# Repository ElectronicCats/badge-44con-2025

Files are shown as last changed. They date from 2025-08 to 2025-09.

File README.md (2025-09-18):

# Hardware config 

Attention! Reading this README is essential—not only for a better understanding and experience, but also to avoid damaging the badge.

The 44con can operate either with the ESP32 or with the shield. It is important to note that, for the badge to function correctly, at least one of the two must be soldered. Otherwise, the badge will not work.

When the shield is installed, the badge will only operate the OLED display with the built-in mini-game.

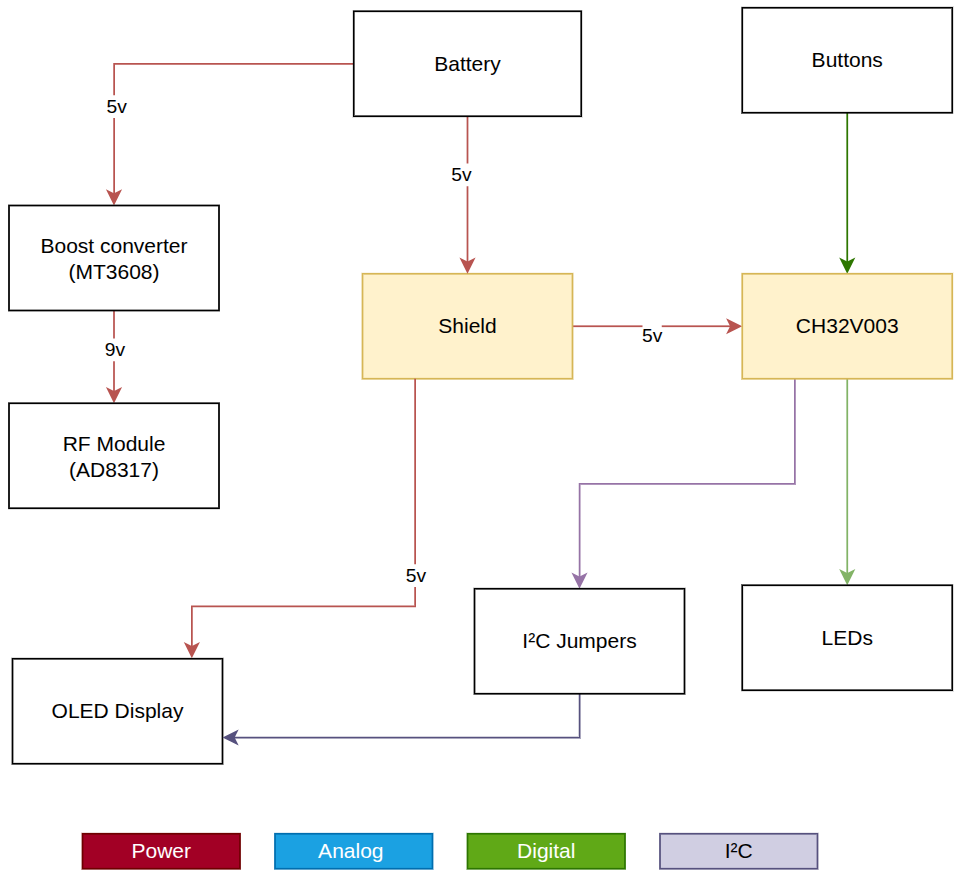
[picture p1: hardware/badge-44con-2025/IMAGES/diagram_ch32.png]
Diagram CH32


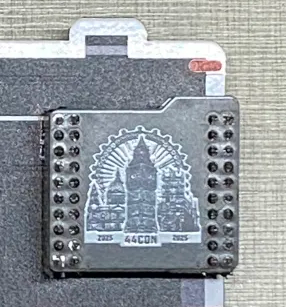
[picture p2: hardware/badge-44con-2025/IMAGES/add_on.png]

(Badge with shield)

# 
If you solder the shield you only need to solder the bended pins shown at the photo at least, if you decide to solder more pins just for fun go ahead.



#
For the best possible experience with the badge, it is recommended to solder the ESP32 with the following components:

ESP32 Wemos D1 module



Buzzer

MT3608 Boost Converter

AD8317 RF Detector

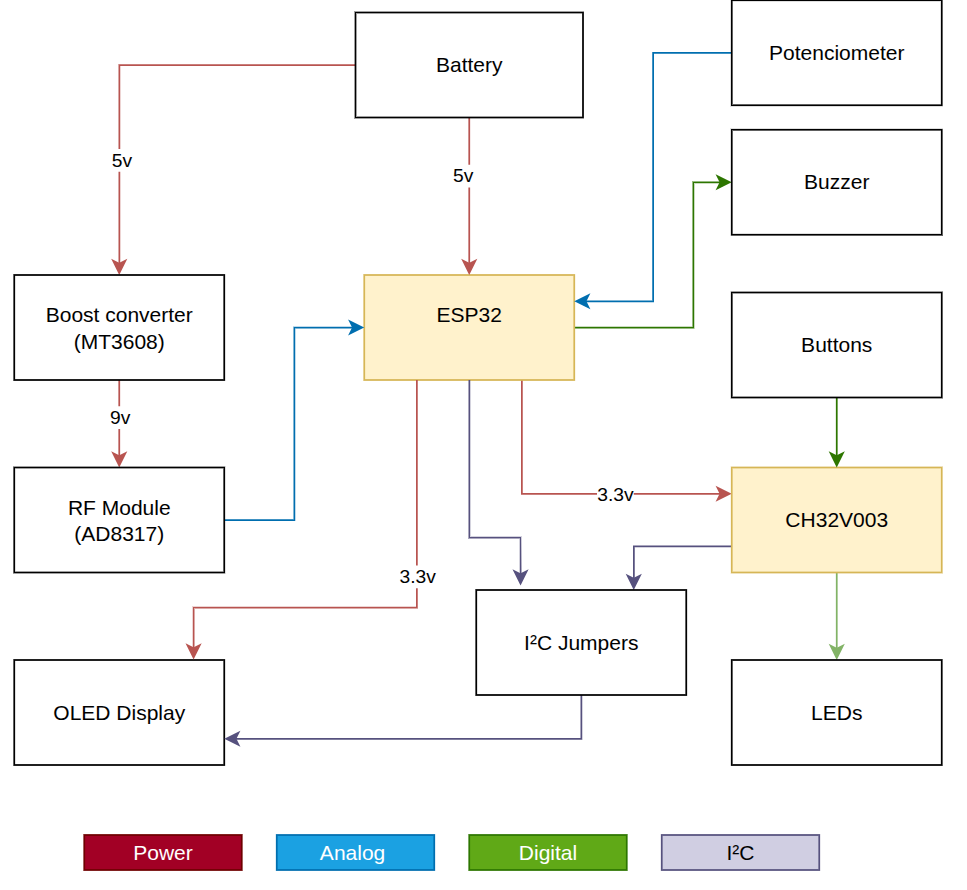
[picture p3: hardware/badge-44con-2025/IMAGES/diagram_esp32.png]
diagram esp32


# Addon 

The Addon is located on the front side of the board, and the connections are as follows:

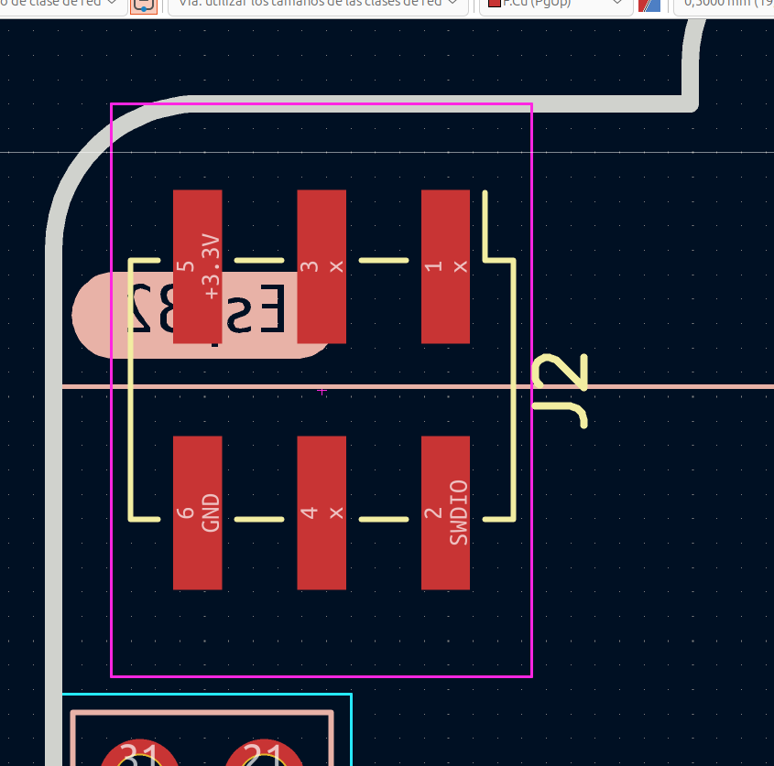
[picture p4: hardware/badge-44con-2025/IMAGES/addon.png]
addon


# Boost circuit
It raises the voltage from 5 V to 9 V for the RF detector. The Boost circuit must be placed on the rear side of the board, as shown in the image. 

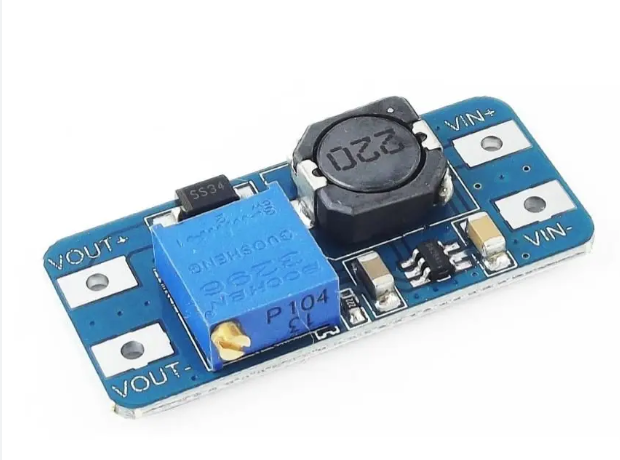
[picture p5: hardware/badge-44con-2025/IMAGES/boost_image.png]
Boost image

<br>
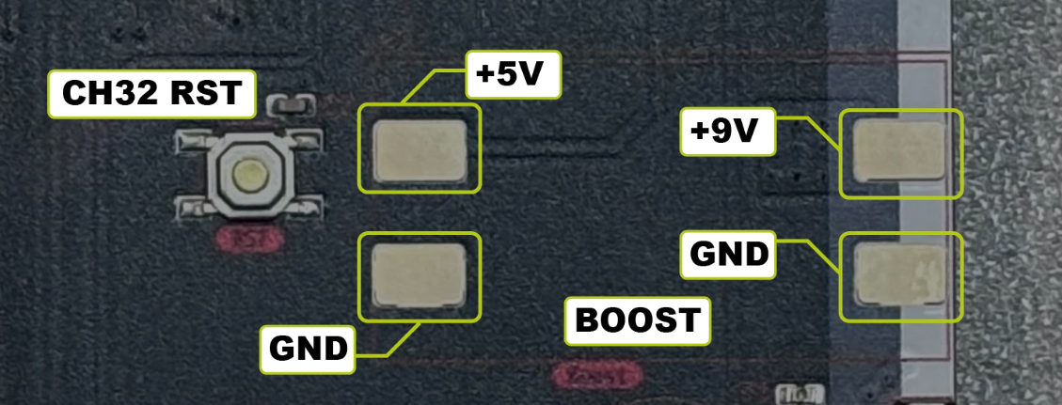
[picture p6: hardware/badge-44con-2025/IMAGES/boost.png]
Boost diagram


# I²C jumper 
The I²C jumpers are located on the rear side of the board (JP3 for SCL and JP2 for SDA). These determine whether the ESP32 or the CH32 will control the OLED display. By default, the CH32 controls the display. To switch control to the ESP32, the pads must be cut to separate them (as indicated in the image), and then the central pad must be soldered to the opposite pad. In the case of JP2, solder the central pad to the left pad, and for JP3, solder it to the right pad.

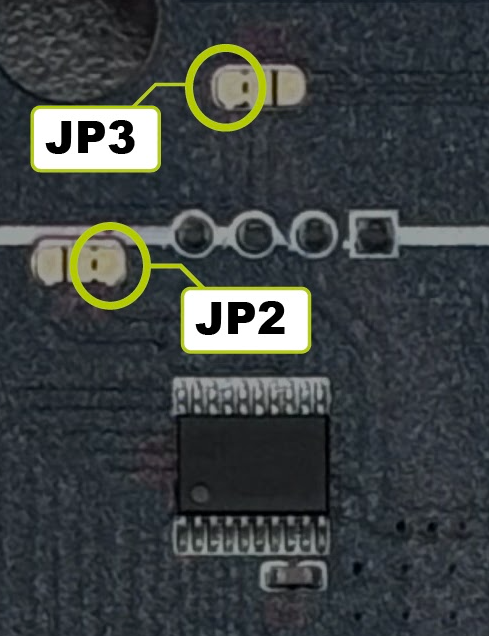
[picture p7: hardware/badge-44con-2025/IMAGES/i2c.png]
I2C Diagram


# Potenciometer
The potentiometer must be installed on the rear side of the board, ensuring that its notch fits into the corresponding slot, allowing the value to be adjusted from the front side of the PCB. 

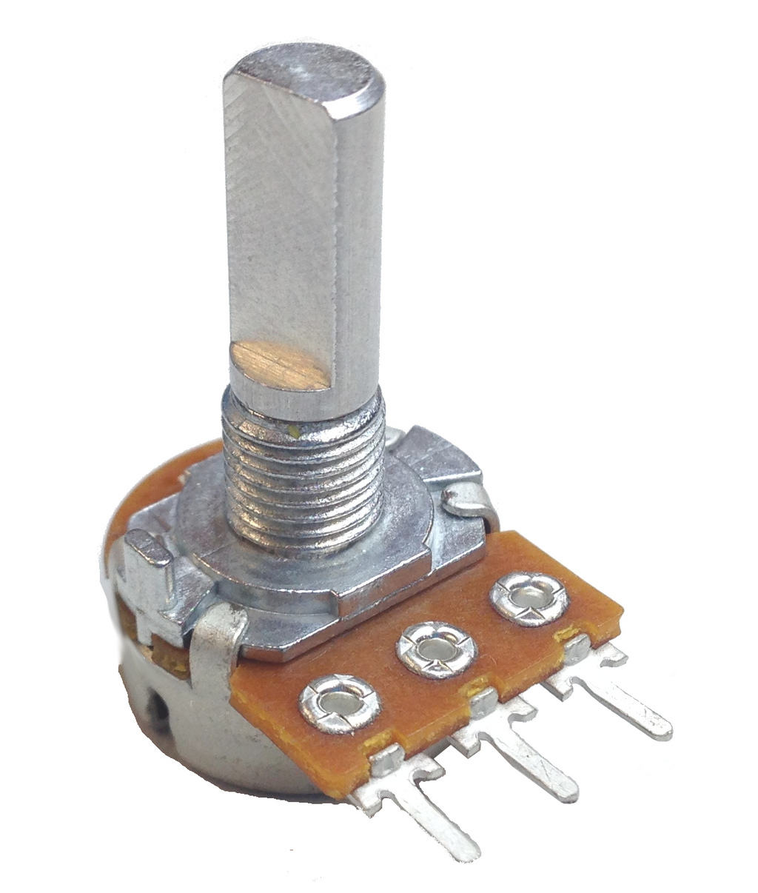
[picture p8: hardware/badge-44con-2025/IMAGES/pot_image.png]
Potentiometer Image

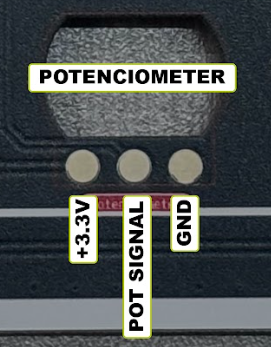
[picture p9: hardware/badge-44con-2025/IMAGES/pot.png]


This is how it should look, front and back.

Potentiometer Back
Potentiometer Front

# Buzzer
For the buzzer, please solder it as follows:

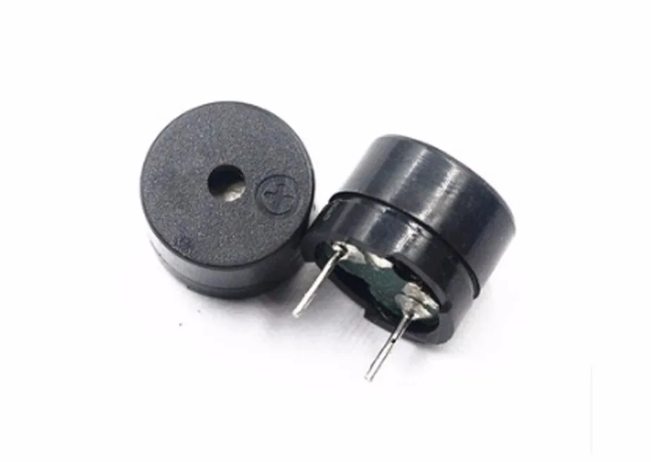
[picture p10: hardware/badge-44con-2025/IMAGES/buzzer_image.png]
Buzzer Image

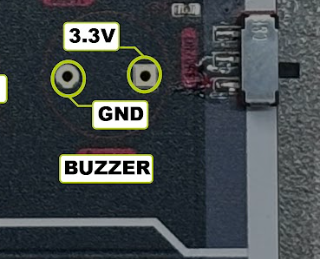
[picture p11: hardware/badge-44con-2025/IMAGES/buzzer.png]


# RF Detector 
It detects hidden wireless devices by measuring RF signal strength and displaying results on an OLED screen, with optional buzzer alerts.

The RF detector must be placed on the rear side of the PCB, as shown in the image. IMPORTANT: Before soldering the RF module, first solder the Boost circuit and configure its voltage to 9 V to ensure proper operation of the RF detector and prevent damage. The PCB has the supply voltage (9VA) disconnected via JP1 to avoid damage. Only bridge it after confirming that the voltage is correct.
For more information about the functionality, please refer to the following repository: https://github.com/RamboRogers/rfhunter

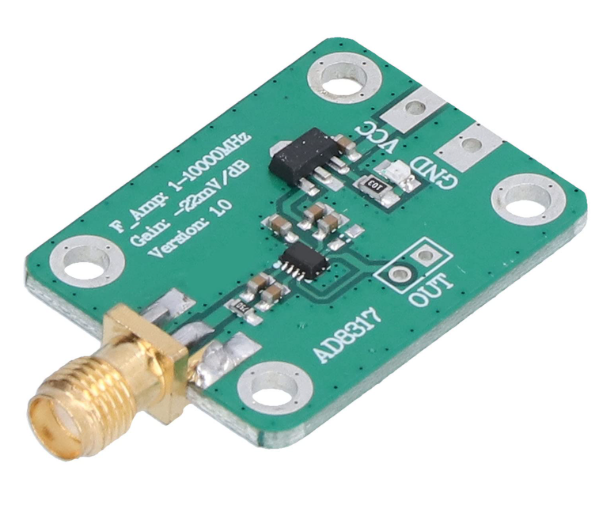
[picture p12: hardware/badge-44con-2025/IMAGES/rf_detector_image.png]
RF Detector Image

<br>
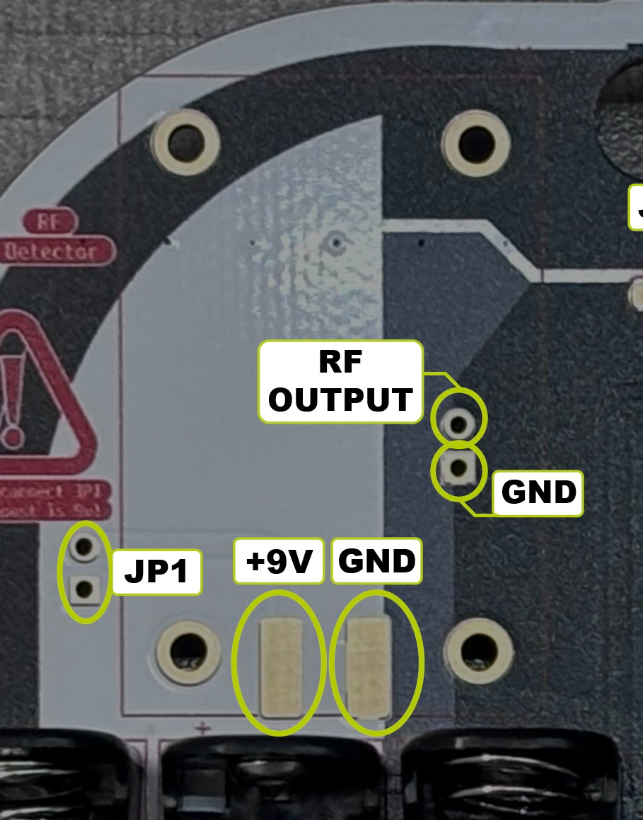
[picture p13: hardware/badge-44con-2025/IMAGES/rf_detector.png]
RF Detector Diagram


This project uses and builds upon the work of rfhunter by RamboRogers.

The original firmware and repository can be found here: https://github.com/RamboRogers/rfhunter

We acknowledge and thank the original author for making this project available!

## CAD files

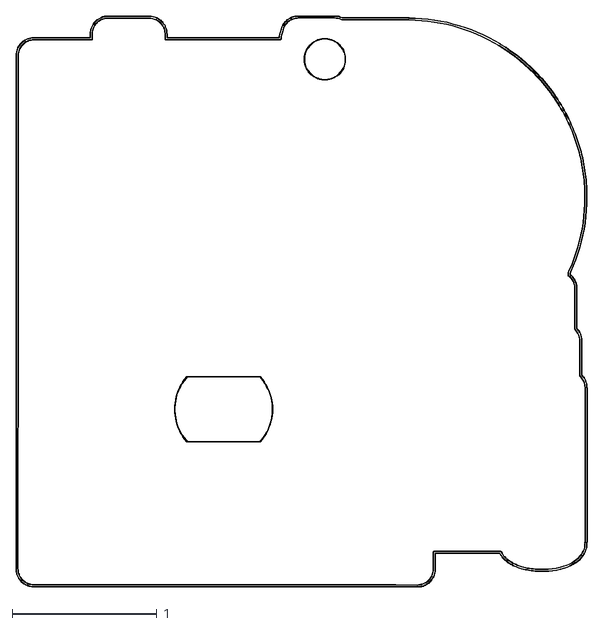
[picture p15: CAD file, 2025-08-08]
hardware/badge-44con-2025/badge-44con-2025-Edge_Cuts.dxf
3.95 x 3.95

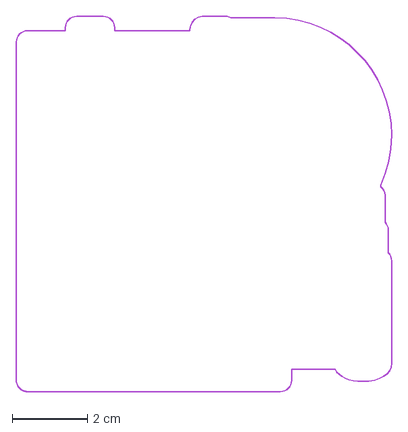
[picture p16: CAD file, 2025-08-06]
hardware/badge-44con-2025/10X10_CONTORNO BADGE 44CON 25.dxf
10.00 x 10.00 cm

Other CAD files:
hardware/badge-44con-2025/badge-44con-2025-B_Silkscreen.dxf
hardware/badge-44con-2025/badge-44con-2025-F_Silkscreen.dxf

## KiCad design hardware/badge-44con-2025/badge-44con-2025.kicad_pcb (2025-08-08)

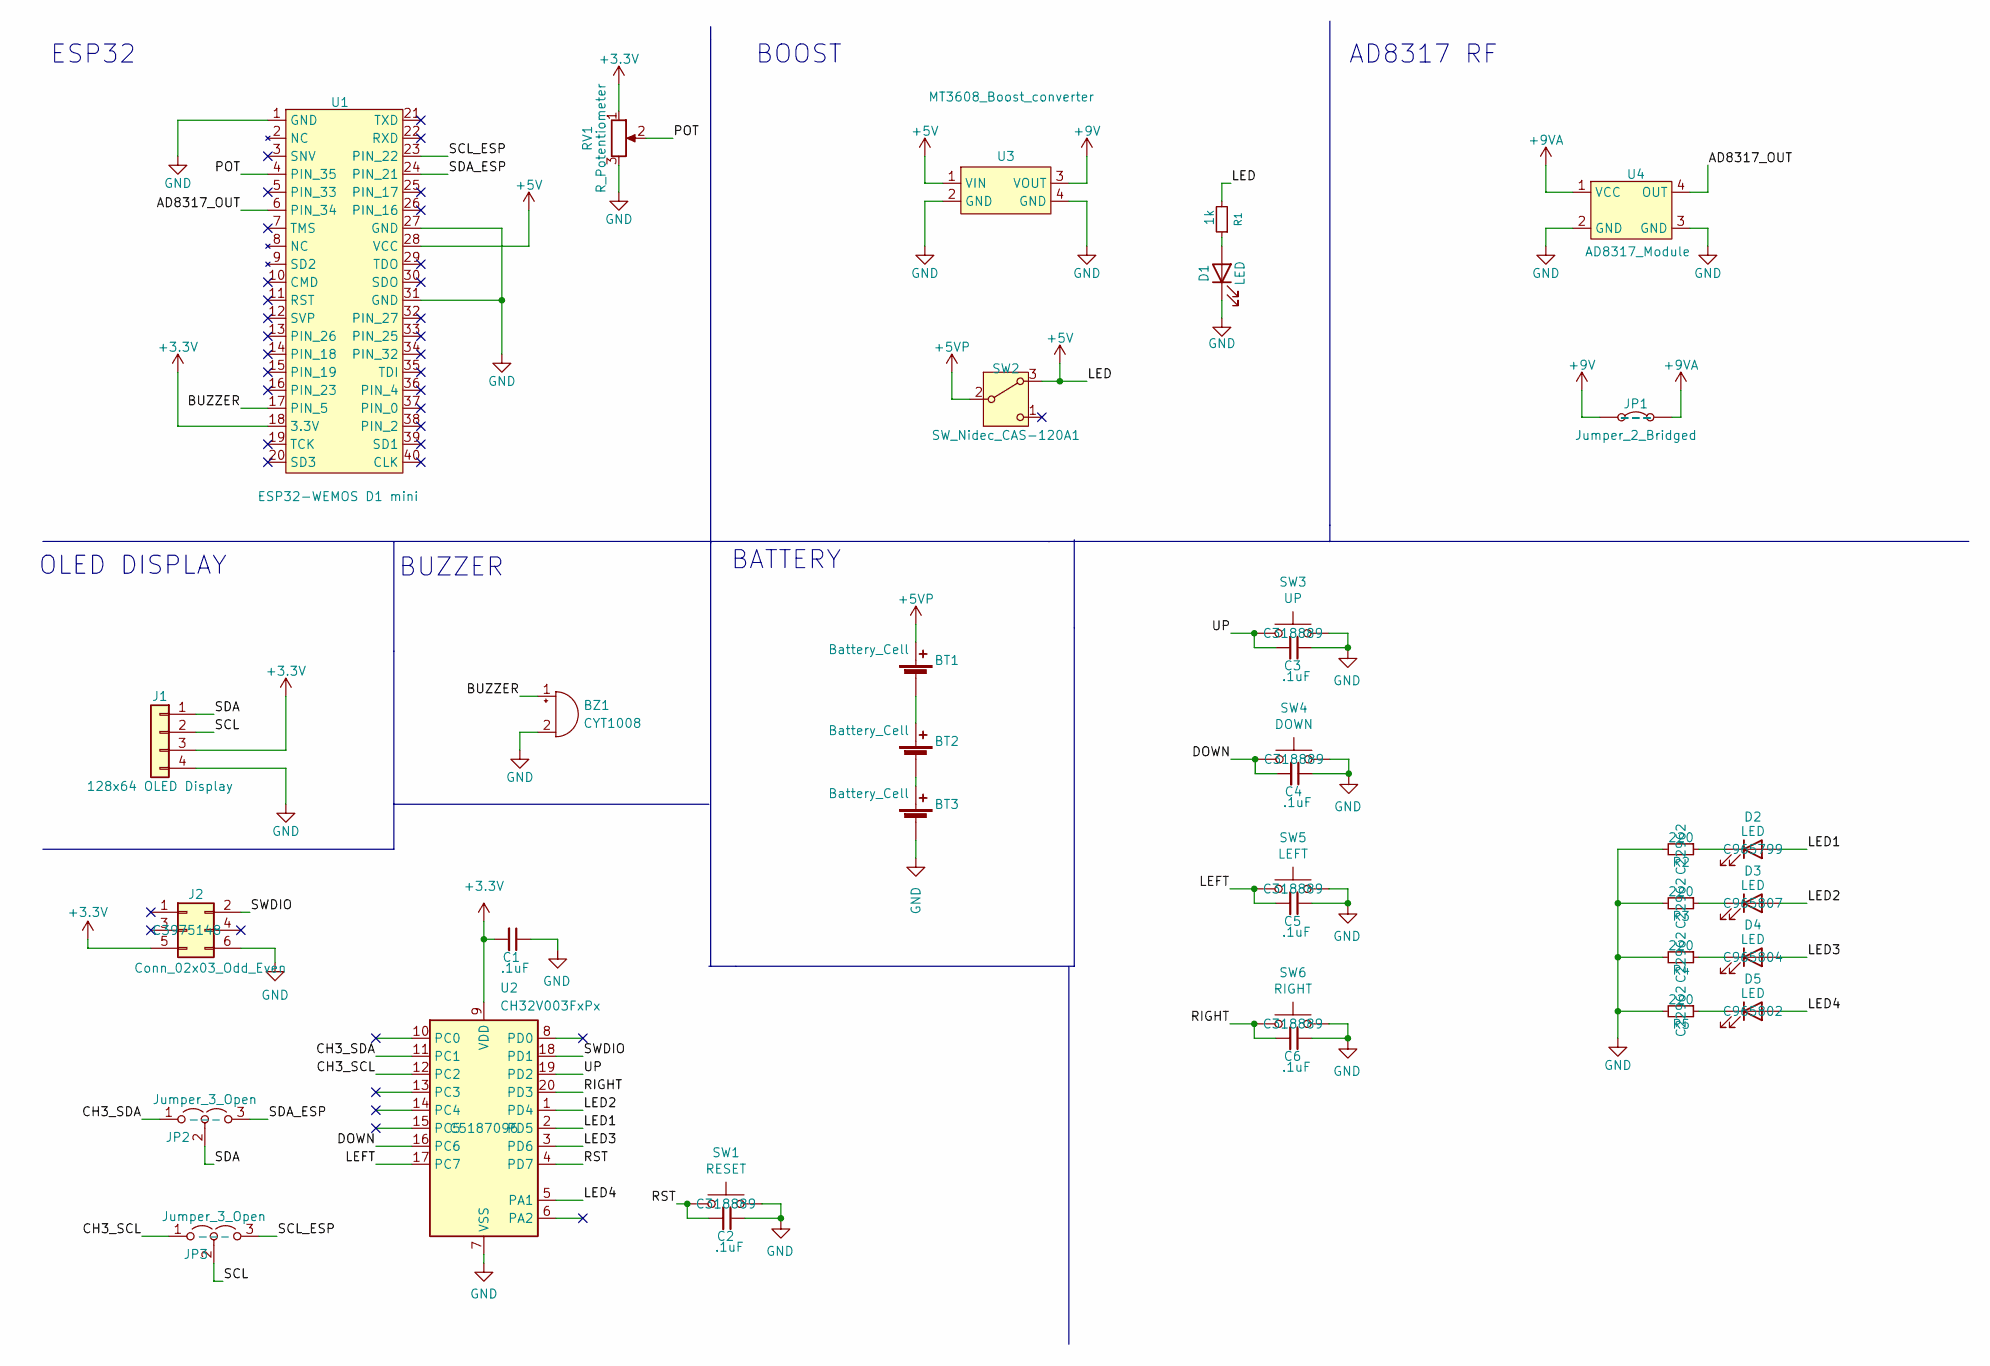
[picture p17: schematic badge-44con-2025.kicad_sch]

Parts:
BT1, BT2, BT3: Battery_Cell; BatteryHolder_Keystone_2466_1xAAA; LCSC# C5290189
BZ1: CYT1008; Buzzer_12x9.5RM7.6
C1, C2, C3, C4, C5, C6: .1uF; C_0603_1608Metric; LCSC# C478888
D1: LED; LED_0603_1608Metric
D2: LED; LED_0603_1608Metric; LCSC# C965799
D3: LED; LED_0603_1608Metric; LCSC# C965807
D4: LED; LED_0603_1608Metric; LCSC# C965804
D5: LED; LED_0603_1608Metric; LCSC# C965802
J1: 128x64 OLED Display; MODULE_DM-OLED096-636
J2: Conn_02x03_Odd_Even; PinHeader_2x03_P2.54mm_Vertical_SMD; LCSC# C3975148
JP1: Jumper_2_Bridged; PinHeader_1x02_P2.54mm_Vertical
JP2, JP3: Jumper_3_Open; SolderJumper-3_P1.3mm_Bridged2Bar12_RoundedPad1.0x1.5mm
R1: 1k; R_0603_1608Metric
R2, R3, R4, R5: 220; R_0603_1608Metric; LCSC# C22962
RV1: R_Potentiometer; Potentiometer_generic
SW1: RESET; SW_SPST_TL3342; LCSC# C318889
SW2: SW_Nidec_CAS-120A1; JS102011SAQN
SW3: UP; SW_SPST_TL3342; LCSC# C318889
SW4: DOWN; SW_SPST_TL3342; LCSC# C318889
SW5: LEFT; SW_SPST_TL3342; LCSC# C318889
SW6: RIGHT; SW_SPST_TL3342; LCSC# C318889
U1: ESP32-WEMOS D1 mini; Wemos Mini D1 ESP WiFi + Bluetooth CP2104
U2: CH32V003FxPx; TSSOP-20_4.4x6.5mm_P0.65mm; LCSC# C5187096
U3: MT3608_Boost_converter; MT3608
U4: AD8317_Module; AD8317

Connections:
+3.3V: C1.2, J1.3, J2.5, RV1.1, U1.18 (3.3V), U2.9 (VDD)
+5V: R1.2, SW2.3 (A), U1.28 (VCC), U3.1 (VIN)
+5VP: BT1.1 (+), SW2.2 (B)
+9V: JP1.1 (A), U3.3 (VOUT)
+9VA: JP1.2 (B), U4.1 (VCC)
/AD8317_OUT: U1.6 (PIN_34), U4.4 (OUT)
/BUZZER: BZ1.1 (+), U1.17 (PIN_5)
/CH3_SCL: JP3.1 (A), U2.12 (PC2)
/CH3_SDA: JP2.1 (A), U2.11 (PC1)
/DOWN: C4.2, SW4.2, U2.16 (PC6)
/LED1: D2.2 (A), U2.2 (PD5)
/LED2: D3.2 (A), U2.1 (PD4)
/LED3: D4.2 (A), U2.3 (PD6)
/LED4: D5.2 (A), U2.5 (PA1)
/LEFT: C5.2, SW5.2, U2.17 (PC7)
/POT: RV1.2, U1.4 (PIN_35)
/RIGHT: C6.2, SW6.2, U2.20 (PD3)
/RST: C2.2, SW1.2, U2.4 (PD7)
/SCL: J1.2, JP3.2 (C)
/SCL_ESP: JP3.3 (B), U1.23 (PIN_22)
/SDA: J1.1, JP2.2 (C)
/SDA_ESP: JP2.3 (B), U1.24 (PIN_21)
/SWDIO: J2.2, U2.18 (PD1)
/UP: C3.2, SW3.2, U2.19 (PD2)
GND: BT3.2 (-), BZ1.2 (-), C1.1, C2.1, C3.1, C4.1, C5.1, C6.1, D1.1 (K), J1.4, J2.6, R2.2, R3.2, R4.2, R5.2, RV1.3, SW1.1, SW3.1, SW4.1, SW5.1, SW6.1, U1.1 (GND), U1.27 (GND), U1.31 (GND), U2.7 (VSS), U3.2 (GND), U3.4 (GND), U4.2 (GND), U4.3 (GND)
unnamed: BT1.2 (-), BT2.1 (+)
unnamed: BT2.2 (-), BT3.1 (+)
unnamed: D1.2 (A), R1.1
unnamed: D2.1 (K), R2.1
unnamed: D3.1 (K), R3.1
unnamed: D4.1 (K), R4.1
unnamed: D5.1 (K), R5.1

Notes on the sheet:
AD8317 RF
BATTERY
ESP32
BUZZER
BOOST
OLED DISPLAY

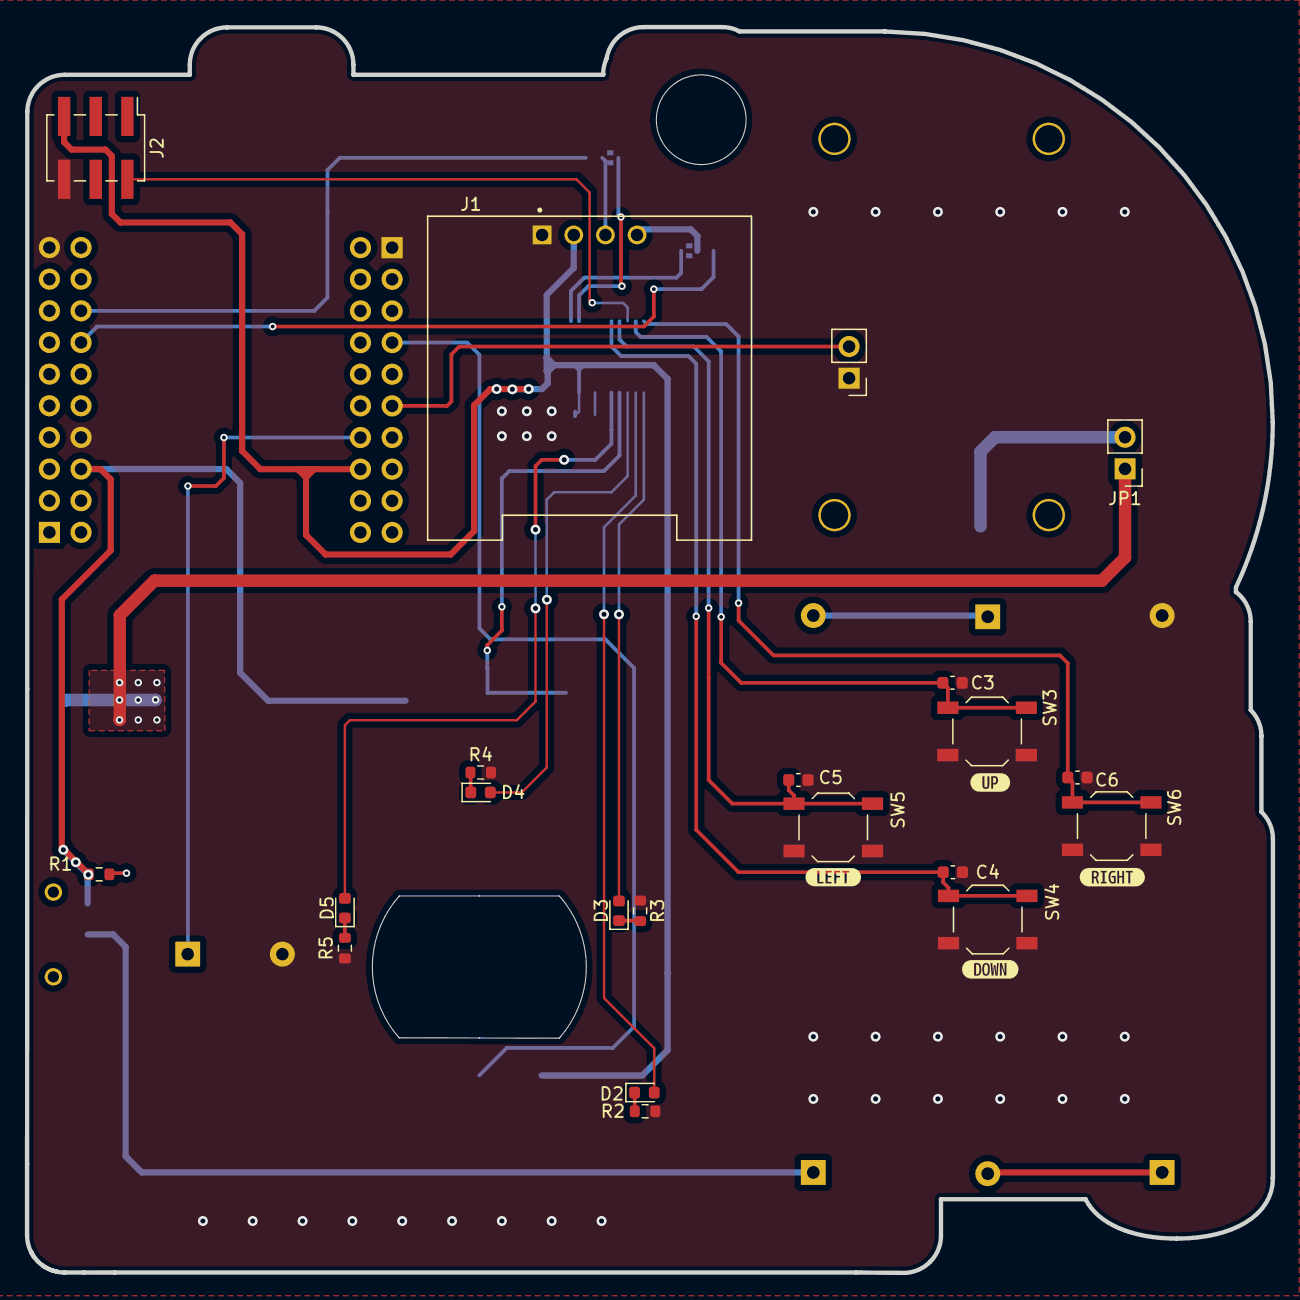
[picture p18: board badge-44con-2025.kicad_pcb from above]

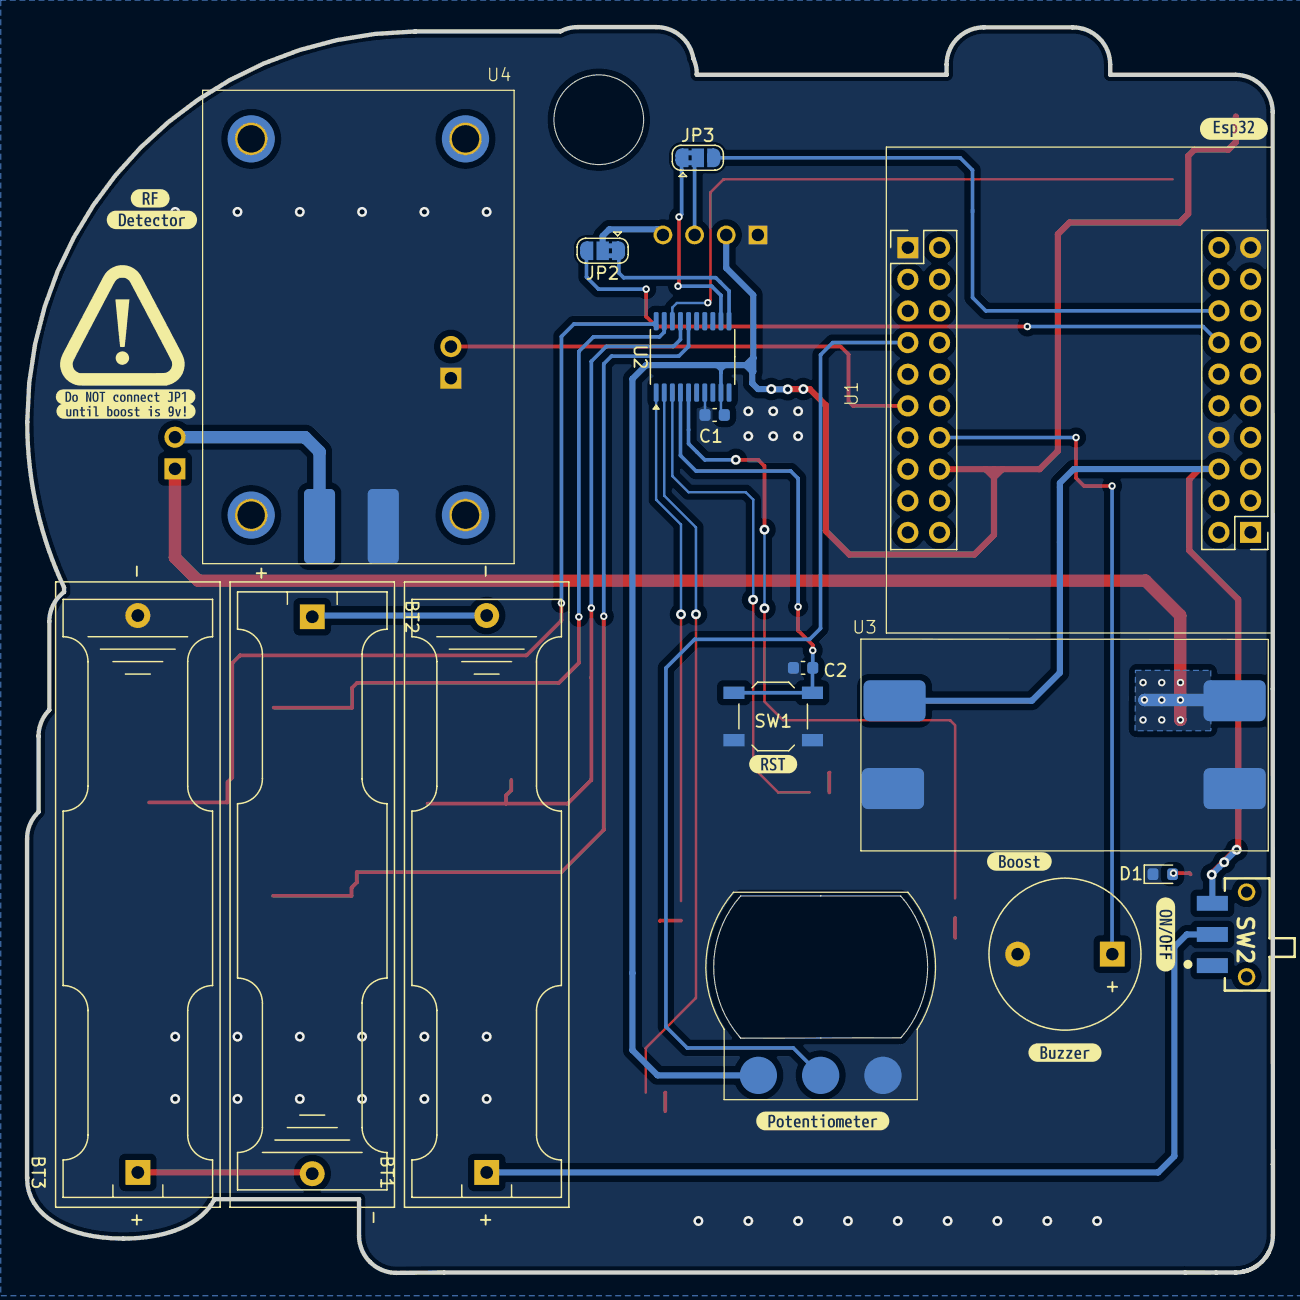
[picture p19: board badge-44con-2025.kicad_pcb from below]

Board: 2 copper layers, 100.0 x 100.0 mm, 50 parts (25 on the bottom side), 32 nets.

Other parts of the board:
kibuzzard-68957B6E: G***; kibuzzard-68957B6E
kibuzzard-68957F6B: G***; kibuzzard-68957F6B
kibuzzard-689576B7: G***; kibuzzard-689576B7
kibuzzard-689576CB: G***; kibuzzard-689576CB
kibuzzard-689576F4: G***; kibuzzard-689576F4
kibuzzard-689576FF: G***; kibuzzard-689576FF
kibuzzard-689581B6: G***; kibuzzard-689581B6
kibuzzard-689585C0: G***; kibuzzard-689585C0
kibuzzard-689585CD: G***; kibuzzard-689585CD
kibuzzard-689585DD: G***; kibuzzard-689585DD
kibuzzard-689585EE: G***; kibuzzard-689585EE
kibuzzard-6895857B: G***; kibuzzard-6895857B
kibuzzard-68957673: G***; kibuzzard-68957673
kibuzzard-68958540: G***; kibuzzard-68958540

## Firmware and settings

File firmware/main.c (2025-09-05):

/**
 * This is the main project for the badge 44con 
 * 
 * With love from Mexico to you all, this is for you made for Electronic Cats
 * 
 * Credits to:
 *  Electronic Cats Team
 */

#include "ch32fun.h"
#include <stdio.h>
#include "driver.h"
#include "spritebank.h"

// ===================================================================================
// Global Variables
// ===================================================================================
uint8_t LEVELSPEED;
uint8_t GobbingEND;
uint8_t LIVE;
uint8_t INGAME;
uint8_t Gobeactive;
uint8_t TimerGobeactive;
uint8_t add;
uint8_t dotsMem[9];
int8_t dotscount;
uint8_t Frame;

// Save the 
uint8_t leds_on_badge[4] = {
	LED1,
	LED2,
	LED3,
	LED4
};

// This is a counter for every 20 ms 
uint8_t counter_time = 0;

// This is a counter only for the screen
uint8_t oled_counter = 0;
uint8_t state_display_init = 0;
uint8_t once = 0;

// For the waiting sequence
uint8_t number_of_sequence_in_waiting_sequence = 0;

enum
{
    PACMAN = 0,
    FANTOME = 1,
    FRUIT = 2
};

// =================================================================================================
//	FUNCTIONS PROTOTYPES
// =================================================================================================

void ResetVar(void);
void StartGame(PERSONAGE *Sprite);
uint8_t CollisionPac2Caracter(PERSONAGE *Sprite);
void RefreshCaracter(PERSONAGE *Sprite);
uint8_t CheckCollisionWithBack(uint8_t SpriteCheck, uint8_t HorVcheck, PERSONAGE *Sprite);
uint8_t RecupeBacktoCompV(uint8_t SpriteCheck, PERSONAGE *Sprite);
uint8_t Trim(uint8_t Y1orY2, uint8_t TrimValue, uint8_t Decalage);
uint8_t RecupeBacktoCompH(uint8_t SpriteCheck, PERSONAGE *Sprite);
void Tiny_Flip(uint8_t render0_picture1, PERSONAGE *Sprite);
uint8_t FruitWrite(uint8_t x, uint8_t y);
uint8_t LiveWrite(uint8_t x, uint8_t y);
uint8_t DotsWrite(uint8_t x, uint8_t y, PERSONAGE *Sprite);
uint8_t checkDotPresent(uint8_t DotsNumber);
void DotsDestroy(uint8_t DotsNumber);
uint8_t SplitSpriteDecalageY(uint8_t decalage, uint8_t Input, uint8_t UPorDOWN);
uint8_t SpriteWrite(uint8_t x, uint8_t y, PERSONAGE *Sprite);
uint8_t return_if_sprite_present(uint8_t x, PERSONAGE *Sprite, uint8_t SpriteNumber);
uint8_t background(uint8_t x, uint8_t y);
void logo_44con_fun(void);
void turn_off_all_leds();
void turn_on_all_leds();
void leds_display_num(uint8_t num);
void sequence_waiting();
void eat_ghost_sequence(void);
void die_sequence(void);
void new_game_sequence(void);
void new_level_sequence(void);
void display_waiting(void);

// =================================================================================================
//	MAIN FUNCTION
// =================================================================================================
int main(void)
{
    // Setup
    JOY_init();

    // Turn off all leds
    turn_off_all_leds();

    // Loop
	while (1)
    {
        uint8_t t;
        PERSONAGE Sprite[5];
    NEWGAME:
		logo_44con_fun(); // Here is where we gonna put the logo 
        ResetVar();
        LIVE = 3;
        goto New;
    NEWLEVEL:
        if (LEVELSPEED > 10)
        {
            LEVELSPEED = LEVELSPEED - 10;
            if ((LEVELSPEED == 160) || (LEVELSPEED == 120) || (LEVELSPEED == 80) || (LEVELSPEED == 40) || (LEVELSPEED == 10))
            {
                if (LIVE < 3)
                {
                    LIVE++;
                }
            }
        }
    New:
        GobbingEND = (LEVELSPEED / 2);
        for (t = 0; t < 9; t++)
            dotsMem[t] = 0xff;
    RESTARTLEVEL:
        Gobeactive = 0;
        uint8_t *ptr = (uint8_t *)Sprite;
        for (t = 5 * 10; t; t--)
            *ptr++ = 0;
        Sprite[0].type = PACMAN;
        Sprite[0].x = 64;
        Sprite[0].y = 3;
        Sprite[0].Decalagey = 5;
        Sprite[0].DirectionV = 2;
        Sprite[0].DirectionH = 2;
        Sprite[0].DirectionAnim = 0;
        Sprite[1].type = FANTOME;
        Sprite[1].x = 76;
        Sprite[1].y = 4;
        Sprite[1].guber = 0;
        Sprite[2].type = FANTOME;
        Sprite[2].x = 75;
        Sprite[2].y = 5;
        Sprite[2].guber = 0;
        Sprite[3].type = FANTOME;
        Sprite[3].x = 77;
        Sprite[3].y = 4;
        Sprite[3].guber = 0;
        Sprite[4].type = FANTOME;
        Sprite[4].x = 76;
        Sprite[4].y = 5;
        Sprite[4].guber = 0;
        while (1)
        {
            // The game will always starts because it always be true
            if (JOY_act_pressed())
                StartGame(&Sprite[0]);
            if (INGAME)
            {
                if (!JOY_left_pressed())
                    Sprite[0].DirectionV = 0;
                else if (!JOY_right_pressed())
                    Sprite[0].DirectionV = 1;
                if (!JOY_down_pressed())
                    Sprite[0].DirectionH = 1;
                else if (!JOY_up_pressed())
                    Sprite[0].DirectionH = 0;
                // fin joystick
                if (TimerGobeactive > 1)
                    TimerGobeactive--;
                else if (TimerGobeactive == 1)
                {
                    TimerGobeactive = 0;
                    Gobeactive = 0;
                }
                eat_ghost_sequence();
            }
            
            if (Frame < 24)
                Frame++;
            else
                Frame = 0;
            if (CollisionPac2Caracter(&Sprite[0]) == 0)
                RefreshCaracter(&Sprite[0]);
            else
            {
                die_sequence();
                // Here we die
                if (LIVE > 0)
                {
                    LIVE--;
                    goto RESTARTLEVEL;
                }
                else{
                    new_game_sequence();
                    goto NEWGAME;
                }
            }
            if (Frame % 2 == 0)
            {
                Tiny_Flip(0, &Sprite[0]);
            }
            else
            {
                for (t = 0; t < 63; t++)
                {
                    if (checkDotPresent(t))
                        break;
                    else if (t == 62)
                    {   
                        new_level_sequence();
                        goto NEWLEVEL;
                    }
                }
            }

            // Delay in the game
            JOY_SLOWDOWN();
        }
    }
}

// ===================================================================================
// 44con functions
// ===================================================================================

// Function to wait for the 
void logo_44con_fun(void)
{
	while (!JOY_START())
	{
        display_waiting();
        sequence_waiting();
		JOY_SLOWDOWN();
	}
    number_of_sequence_in_waiting_sequence = 0;
    counter_time = 0;
    turn_off_all_leds();
}

void turn_off_all_leds()
{
    for(uint8_t i = 0; i<4; i++){
        funDigitalWrite(leds_on_badge[i],0);
    }
}

void turn_on_all_leds()
{
    for(uint8_t i = 0; i<4; i++){
        funDigitalWrite(leds_on_badge[i],1);
    }
}

void leds_display_num(uint8_t num)
{
    if(num>3) return;

    turn_off_all_leds();
    funDigitalWrite(leds_on_badge[num],1);
}

void sequence_waiting()
{
    // Every 500 ms, this counter is to get the 
    if(counter_time == 10){
        if(number_of_sequence_in_waiting_sequence < 8)
        {
            leds_display_num(number_of_sequence_in_waiting_sequence%4);
        }
        else if(number_of_sequence_in_waiting_sequence > 7 && number_of_sequence_in_waiting_sequence < 12)
        {
            funDigitalWrite(leds_on_badge[number_of_sequence_in_waiting_sequence - 8], 1);
        }
        else if(number_of_sequence_in_waiting_sequence > 11 && number_of_sequence_in_waiting_sequence < 16)
        {
            funDigitalWrite(leds_on_badge[number_of_sequence_in_waiting_sequence - 12], 0);
        }
        else if (number_of_sequence_in_waiting_sequence > 15)
        {
            leds_display_num(3 - (number_of_sequence_in_waiting_sequence%4));
        }
        number_of_sequence_in_waiting_sequence++;
        if(number_of_sequence_in_waiting_sequence == 24){
            number_of_sequence_in_waiting_sequence = 0;
        }
        counter_time = 0;
    }

    counter_time++;
}

void display_waiting(void)
{
    switch (state_display_init)
    {
    case 0:
        if(once){
            OLED_draw_bmp(0, 0, 128, 8, logo_44Con);
            once = 0;
        }

        oled_counter++;

        if(oled_counter > 100){
            oled_counter = 0;
            state_display_init = 1;
            once = 1;
        }

        break;

    case 1:

        if(once){
            OLED_draw_bmp(0, 0, 128, 8, logo_44Con_Inverted);
            once = 0;
        }

        oled_counter++;

        if(oled_counter > 20){
            oled_counter = 0;
            state_display_init = 0;
            once = 1;
        }

        break;
    
    default:
        break;
    }
    oled_counter++;
}

void eat_ghost_sequence(void)
{
    // This part is a condition when the pacman can eat the ghots
    if (Gobeactive)
    {
        funDigitalWrite(LED2,1);
    }
    else
    {
        funDigitalWrite(LED2,0);
    }
}

void die_sequence(void)
{
    // Turn off all leds
    turn_off_all_leds();

    // If we die this will show on the red led
    for(uint8_t i = 0; i<4; i++){
        leds_display_num(0);
        JOY_DLY_ms(150);
        turn_off_all_leds();
        JOY_DLY_ms(150);
    }
}

void new_game_sequence(void)
{
    for(uint8_t i = 0; i<2; i++){
        turn_on_all_leds();
        JOY_DLY_ms(500);
        turn_off_all_leds();
        JOY_DLY_ms(500);
    }
}

void new_level_sequence(void)
{
    // Sequence on leds when you pass the PACMAN GAME
    for(uint8_t i = 0; i<2; i++){
        for(uint8_t j = 0; j<4; j++){
            funDigitalWrite(leds_on_badge[j],1);
            JOY_DLY_ms(200);
        }
        turn_off_all_leds();
        JOY_DLY_ms(200);
    }
}

// ===================================================================================
// Functions
// ===================================================================================
void ResetVar(void)
{
    LEVELSPEED = 200;
    GobbingEND = 0;
    LIVE = 3;
    Gobeactive = 0;
    TimerGobeactive = 0;
    add = 0;
    INGAME = 0;
    for (uint8_t t = 0; t < 9; t++)
    {
        dotsMem[t] = 0xff;
    }
    dotscount = 0;
    Frame = 0;
}

void StartGame(PERSONAGE *Sprite)
{
    if (INGAME == 0)
    {
        Sprite[1].x = 76;
        Sprite[1].y = 3;
        Sprite[2].x = 75;
        Sprite[2].y = 4;
        Sprite[3].x = 77;
        Sprite[3].y = 3;
        Sprite[4].x = 76;
        Sprite[4].y = 4;
        INGAME = 1;
    }
}

uint8_t CollisionPac2Caracter(PERSONAGE *Sprite)
{
    uint8_t ReturnCollision = 0;
#define xmax(I) (Sprite[I].x + 6)
#define xmin(I) (Sprite[I].x)
#define ymax(I) ((Sprite[I].y * 8) + Sprite[I].Decalagey + 6)
#define ymin(I) ((Sprite[I].y * 8) + Sprite[I].Decalagey)
    if ((INGAME))
    {
        for (uint8_t t = 1; t <= 4; t++)
        {
            if ((xmax(0) < xmin(t)) || (xmin(0) > xmax(t)) || (ymax(0) < ymin(t)) || (ymin(0) > ymax(t)))
            {
            }
            else
            {
                if (Gobeactive)
                {
                    // Here is when the ghosts can be eaten
                    if (Sprite[t].guber != 1)
                    {
                        funDigitalWrite(LED3, 1);
                        JOY_DLY_ms(15);
                        funDigitalWrite(LED3, 0);
                    }
                    Sprite[t].guber = 1;
                    ReturnCollision = 0;
                }
                else
                {   
                    if (Sprite[t].guber == 1)
                    {
                        ReturnCollision = 0;
                    }
                    else
                    {
                        ReturnCollision = 1;
                    }
                }
            }
        }
    }
    return ReturnCollision;
}

void RefreshCaracter(PERSONAGE *Sprite)
{
    uint8_t memx, memy, memdecalagey;
    for (uint8_t t = 0; t <= 4; t++)
    {
        memx = Sprite[t].x;
        memy = Sprite[t].y;
        memdecalagey = Sprite[t].Decalagey;
        if ((Sprite[t].y > -1) && (Sprite[t].y < 8))
        {
            if ((Frame % 2 == 0) || (t == 0) || (LEVELSPEED <= 160))
            {
                if (Sprite[t].DirectionV == 1)
                {
                    Sprite[t].x++;
                }
                if (Sprite[t].DirectionV == 0)
                {
                    if (t == 0)
                    {
                        if ((Sprite[0].y == 3) && (Sprite[0].x == 86))
                        {
                        }
                        else
                        {
                            Sprite[t].x--;
                        }
                    }
                    else
                    {
                        Sprite[t].x--;
                    }
                }
            }
        }
        if (CheckCollisionWithBack(t, 1, Sprite))
        {
            if (t != 0)
            {
                Sprite[t].DirectionV = JOY_random() % 2;
            }
            else
            {
                Sprite[t].DirectionV = 2;
            }
            Sprite[t].x = memx;
        }
        if ((Frame % 2 == 0) || (t == 0) || (LEVELSPEED <= 160))
        {
            if (Sprite[t].DirectionH == 1)
            {
                if (Sprite[t].Decalagey < 7)
                {
                    Sprite[t].Decalagey++;
                }
                else
                {
                    Sprite[t].Decalagey = 0;
                    Sprite[t].y++;
                    if (Sprite[t].y == 9)
                    {
                        Sprite[t].y = -1;
                    }
                }
            }
            if (Sprite[t].DirectionH == 0)
            {
                if (Sprite[t].Decalagey > 0)
                {
                    Sprite[t].Decalagey--;
                }
                else
                {
                    Sprite[t].Decalagey = 7;
                    Sprite[t].y--;
                    if (Sprite[t].y == -2)
                    {
                        Sprite[t].y = 8;
                    }
                }
            }
        }
        if (CheckCollisionWithBack(t, 0, Sprite))
        {
            if (t != 0)
            {
                Sprite[t].DirectionH = JOY_random() % 2;
            }
            else
            {
                Sprite[t].DirectionH = 2;
            }
            Sprite[t].y = memy;
            Sprite[t].Decalagey = memdecalagey;
        }
        if (t == 0)
        {
            if (Frame % 2 == 0)
            {
                if (Sprite[t].DirectionH == 1)
                {
                    Sprite[t].DirectionAnim = 0;
                }
                if (Sprite[t].DirectionH == 0)
                {
                    Sprite[t].DirectionAnim = (2 * 3);
                }
                if (Sprite[t].DirectionV == 1)
                {
                    Sprite[t].DirectionAnim = (3 * 3);
                }
                if (Sprite[t].DirectionV == 0)
                {
                    Sprite[t].DirectionAnim = (1 * 3);
                }
            }
        }
        else
        {
            if ((Frame == 0) || (Frame == 12))
            {
                Sprite[t].DirectionAnim = 0;
                if (Sprite[t].DirectionH == 1)
                {
                    Sprite[t].DirectionAnim = 0;
                }
                if (Sprite[t].DirectionH == 0)
                {
                    Sprite[t].DirectionAnim = 2;
                }
            }
        }
        if (t == 0)
        {
            if (Frame % 2 == 0)
            {
                if (Sprite[0].switchanim == 0)
                {
                    if (Sprite[0].anim < 2)
                    {
                        Sprite[0].anim++;
                    }
                    else
                    {
                        Sprite[0].switchanim = 1;
                    }
                }
                else
                {
                    if (Sprite[0].anim > 0)
                    {
                        Sprite[0].anim--;
                    }
                    else
                    {
                        Sprite[0].switchanim = 0;
                    }
                }
            }
        }
        else
        {
            if ((Sprite[t].guber == 1) && (Sprite[t].x >= 74) && (Sprite[t].x <= 76) && (Sprite[t].y >= 2) && (Sprite[t].y <= 4))
            {
                Sprite[t].guber = 0;
            }
            if (Frame % 2 == 0)
            {
                if (Sprite[t].anim < 1)
                {
                    Sprite[t].anim++;
                }
                else
                {
                    Sprite[t].anim = 0;
                }
            }
        }
    }
}

uint8_t CheckCollisionWithBack(uint8_t SpriteCheck, uint8_t HorVcheck, PERSONAGE *Sprite)
{
    uint8_t BacktoComp;
    if (HorVcheck == 1)
    {
        BacktoComp = RecupeBacktoCompV(SpriteCheck, Sprite);
    }
    else
    {
        BacktoComp = RecupeBacktoCompH(SpriteCheck, Sprite);
    }
    if ((BacktoComp) != 0)
    {
        return 1;
    }
    else
    {
        return 0;
    }
}

uint8_t RecupeBacktoCompV(uint8_t SpriteCheck, PERSONAGE *Sprite)
{
    uint8_t Y1 = 0b00000000;
    uint8_t Y2 = Y1;
#define SpriteWide 6
#define MAXV (Sprite[SpriteCheck].x + SpriteWide)
#define MINV (Sprite[SpriteCheck].x)
    if (Sprite[SpriteCheck].DirectionV == 1)
    {
        Y1 = (back[((Sprite[SpriteCheck].y) * 128) + (MAXV)]);
        Y2 = (back[((Sprite[SpriteCheck].y + 1) * 128) + (MAXV)]);
    }
    else if (Sprite[SpriteCheck].DirectionV == 0)
    {
        Y1 = (back[((Sprite[SpriteCheck].y) * 128) + (MINV)]);
        Y2 = (back[((Sprite[SpriteCheck].y + 1) * 128) + (MINV)]);
    }
    else
    {
        Y1 = 0;
        Y2 = 0;
    }
    // decortique
    Y1 = Trim(0, Y1, Sprite[SpriteCheck].Decalagey);
    Y2 = Trim(1, Y2, Sprite[SpriteCheck].Decalagey);
    if (((Y1) != 0b00000000) || ((Y2) != 0b00000000))
    {
        return 1;
    }
    else
    {
        return 0;
    }
}

uint8_t Trim(uint8_t Y1orY2, uint8_t TrimValue, uint8_t Decalage)
{
    uint8_t Comp;
    if (Y1orY2 == 0)
    {
        Comp = 0b01111111 << Decalage;
        return (TrimValue & Comp);
    }
    else
    {
        Comp = (0b01111111 >> (8 - Decalage));
        return (TrimValue & Comp);
    }
}

uint8_t ScanHRecupe(uint8_t UporDown, uint8_t Decalage)
{
    if (UporDown == 0)
    {
        return 0b01111111 << Decalage;
    }
    else
    {
        return 0b01111111 >> (8 - Decalage);
    }
}

uint8_t RecupeBacktoCompH(uint8_t SpriteCheck, PERSONAGE *Sprite)
{
    uint8_t TempPGMByte;
    if (Sprite[SpriteCheck].DirectionH == 0)
    {
        uint8_t RECUPE = (ScanHRecupe(0, Sprite[SpriteCheck].Decalagey));
        for (uint8_t t = 0; t <= 6; t++)
        {
            if ((((Sprite[SpriteCheck].y) * 128) + (Sprite[SpriteCheck].x + t) > 1023) || (((Sprite[SpriteCheck].y) * 128) + (Sprite[SpriteCheck].x + t) < 0))
            {
                TempPGMByte = 0x00;
            }
            else
            {
                TempPGMByte = ((back[((Sprite[SpriteCheck].y) * 128) + (Sprite[SpriteCheck].x + t)]));
            }
#define CHECKCOLLISION ((RECUPE) & (TempPGMByte))
            if (CHECKCOLLISION != 0)
            {
                return 1;
            }
        }
    }
    else if (Sprite[SpriteCheck].DirectionH == 1)
    {
        uint8_t tadd = 0;
        if (Sprite[SpriteCheck].Decalagey > 2)
        {
            tadd = 1;
        }
        else
        {
            tadd = 0;
        }
        uint8_t RECUPE = (ScanHRecupe(tadd, Sprite[SpriteCheck].Decalagey));
        for (uint8_t t = 0; t <= 6; t++)
        {
            if (((((Sprite[SpriteCheck].y + tadd) * 128) + (Sprite[SpriteCheck].x + t)) > 1023) || ((((Sprite[SpriteCheck].y + tadd) * 128) + (Sprite[SpriteCheck].x + t)) < 0))
            {
                TempPGMByte = 0x00;
            }
            else
            {
                TempPGMByte = (back[((Sprite[SpriteCheck].y + tadd) * 128) + (Sprite[SpriteCheck].x + t)]);
            }
#define CHECKCOLLISION2 ((RECUPE) & (TempPGMByte))
            if (CHECKCOLLISION2 != 0)
            {
                return 1;
            }
        }
    }
    return 0;
}

void Tiny_Flip(uint8_t render0_picture1, PERSONAGE *Sprite)
{
    uint8_t y, x;
    dotscount = -1;
    for (y = 0; y < 8; y++)
    {
        JOY_OLED_data_start(y);
        for (x = 0; x < 128; x++)
        {
            if (render0_picture1 == 0)
            {
                if (INGAME)
                {
                    JOY_OLED_send(background(x, y) | SpriteWrite(x, y, Sprite) | DotsWrite(x, y, Sprite) | LiveWrite(x, y) | FruitWrite(x, y));
                }
                else
                {
                    JOY_OLED_send(0xff - (background(x, y) | SpriteWrite(x, y, Sprite)));
                }
            }
            else if (render0_picture1 == 1)
            {
                JOY_OLED_send((back[x + (y * 128)]));
            }
        }
        JOY_OLED_end();
    }
}

uint8_t FruitWrite(uint8_t x, uint8_t y)
{
    switch (y)
    {
    case 7:
        if (x <= 7)
        {
            return (fruits[x]);
        }
        break;
    case 6:
        if ((LEVELSPEED <= 190) && (x <= 7))
        {
            return (fruits[x + 8]);
        }
        break;
    case 5:
        if ((LEVELSPEED <= 180) && (x <= 7))
        {
            return (fruits[x + 16]);
        }
        break;
    case 4:
        if ((LEVELSPEED <= 170) && (x <= 7))
        {
            return (fruits[x + 24]);
        }
        break;
    }
    return 0;
}
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

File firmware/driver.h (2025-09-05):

#pragma once

#include "ch32fun.h"
#include "oled_min.h"

/**
 * Driver for the game of the badge 44con here comes where it detects the buttons and oled
 * 
 * This functions are adapted for the games from this repository https://github.com/wagiminator/CH32V003-GameConsole
 */

// Buttons in the badge
#define BUTTON_UP       PD2
#define BUTTON_DOWN     PC6
#define BUTTON_LEFT     PC7 
#define BUTTON_RIGHT    PD3

// Leds in the badge
#define LED1    PD5
#define LED2    PD4
#define LED3    PD6
#define LED4    PA1

#define JOY_SOUND 0 // On 0 because there's no buzzer connected in the CH32 chip
#define BUZZER  PC3

#ifdef __cplusplus
extern "C" {
#endif

// Oled defines
#define JOY_OLED_init             OLED_init
#define JOY_OLED_end              I2C_stop
#define JOY_OLED_send(b)          I2C_write(b)
#define JOY_OLED_send_command(c)  OLED_send_command(c)
#define JOY_OLED_data_start(y)    {OLED_setpos(0,y);OLED_data_start();}

// Function to start the gpios and oled for the badge
void JOY_init(void){

    // Init the system
    SystemInit();

    // Init ports
    funGpioInitAll();

    // Set buttons config
    funPinMode(BUTTON_DOWN, GPIO_CNF_IN_PUPD);
    funPinMode(BUTTON_RIGHT, GPIO_CNF_IN_PUPD);
    funPinMode(BUTTON_LEFT, GPIO_CNF_IN_PUPD);
    funPinMode(BUTTON_UP, GPIO_CNF_IN_PUPD);

    // Init buttons
    funDigitalWrite(BUTTON_DOWN,1);
    funDigitalWrite(BUTTON_RIGHT,1);
    funDigitalWrite(BUTTON_LEFT,1);
    funDigitalWrite(BUTTON_UP,1);

    // Set leds config
    funPinMode(LED1, GPIO_Speed_10MHz | GPIO_CNF_OUT_PP);
    funPinMode(LED2, GPIO_Speed_10MHz | GPIO_CNF_OUT_PP);
    funPinMode(LED3, GPIO_Speed_10MHz | GPIO_CNF_OUT_PP);
    funPinMode(LED4, GPIO_Speed_10MHz | GPIO_CNF_OUT_PP);

    #if JOY_SOUND
    funPinMode(BUZZER, GPIO_Speed_10MHz | GPIO_CNF_OUT_PP);
    #endif

    // Init Oled
    OLED_init();
}

#define JOY_act_pressed() 1

uint8_t JOY_START(){
    return !funDigitalRead(BUTTON_UP) || !funDigitalRead(BUTTON_DOWN) || !funDigitalRead(BUTTON_LEFT) || !funDigitalRead(BUTTON_RIGHT); 
} 

uint8_t JOY_up_pressed(void){
    return funDigitalRead(BUTTON_UP);
}

uint8_t JOY_down_pressed(void){
    return funDigitalRead(BUTTON_DOWN);
}

uint8_t JOY_left_pressed(void){
    return funDigitalRead(BUTTON_LEFT);
}

uint8_t JOY_right_pressed(void){
    return funDigitalRead(BUTTON_RIGHT);
}


#define JOY_DLY_ms(n)   Delay_Ms(n)
#define JOY_DLY_us(n)   Delay_Us(n)

#define JOY_SLOWDOWN()    Delay_Ms(20)

// Pseudo random number generator
uint16_t rnval = 0xACE1;
uint16_t JOY_random(void) {
  rnval = (rnval >> 0x01) ^ (-(rnval & 0x01) & 0xB400);
  return rnval;
}

// Buzzer
void JOY_sound(uint8_t freq, uint8_t dur) {
    #if JOY_SOUND 
    while(dur--) {
        JOY_DLY_us(255 - freq);
        funDigitalWrite(BUZZER,1);
        JOY_DLY_us(255 - freq);
        funDigitalWrite(BUZZER,0);
    }
    #endif
}

#ifdef __cplusplus
};
#endif

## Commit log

2025-08-01 feat(Hw): Finished_SCH
    [badge-44con-2025.kicad_sch]
2025-08-06 feat(Hw): floorplan_draft
    [CONTORNO_10CM_BADGE 44CON 25.dxf, badge-44con-2025.kicad_pcb, badge-44con-2025.kicad_sch]
2025-08-06 fix(Hw): Changed_PCB_design
    [10X10_CONTORNO BADGE 44CON 25.dxf, CONTORNO_10CM_BADGE 44CON 25.dxf, badge-44con-2025.kicad_pcb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]
2025-08-07 feat(Hw): Started routing
    [badge-44con-2025.kicad_pcb, badge-44con-2025.kicad_sch]
2025-08-08 feat(Hw): finished_routing
    [badge-44con-2025.kicad_pcb, badge-44con-2025.kicad_sch]
2025-08-08 fix(Hw): fixed_leds_BOM
    [badge-44con-2025-B_Silkscreen.dxf, badge-44con-2025-Edge_Cuts.dxf, badge-44con-2025-F_Silkscreen.dxf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]
2025-09-04 Feat(Hw): Updated_BOM
    [badge-44con-2025.kicad_sch]
2025-09-05 feat: add led sequence for waiting
2025-09-05 feat: add led sequences for the game
2025-09-05 Create Add-on
    [add-on.kicad_pcb, add-on.kicad_sch]
